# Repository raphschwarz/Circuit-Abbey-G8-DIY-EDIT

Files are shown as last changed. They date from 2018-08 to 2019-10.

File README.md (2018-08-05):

# Circuit-Abbey-G8-DIY-EDIT
diy edit for Circuit Abbaye G8 clock divider eurorack module

JACKS CHANGED FOR THONKIKONS

ATMEGA164 package changed to TQFP44//

crystal is thru-hole

MAY2018//74AC244/74LS244 line driver footprint changed to a wider TSSOP to fit most 74LS244 wich are in a wider tssop20 package. 
should still work with the original part (74AC244MTC-ND) but also should fit the more common (SN74LS244DBR)

AUGUST2018// switch has been replaced by TL1105SP (612-TL1105SP-250) as on mutable instruments modules to match thonkikonn jacks height

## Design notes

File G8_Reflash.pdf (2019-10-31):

# G8 Re-Flashing Instructions

The G8 Clock divider uses an embedded processor running a program stored in its internal memory called ‘flash’. Updating this program is hence called ‘re-flashing’. To perform re-flashing you will need:

- The .HEX file to re-flash with
- A programmer compatible with AVRISPII
- A program to drive the programmer

For the program we use AVR Studio 4, mostly because we are used to it. You can use a newer version of AVR Studio, or a different program such as AVR Dude. The programming port is called ‘ISP’. Make sure your programmer can handle ISP. It is characterized by a 6-pin ribbon cable.

Fuse bits:

The fuse bits set processor parameters at program time. Here is a screen capture of AVR Studio 4:

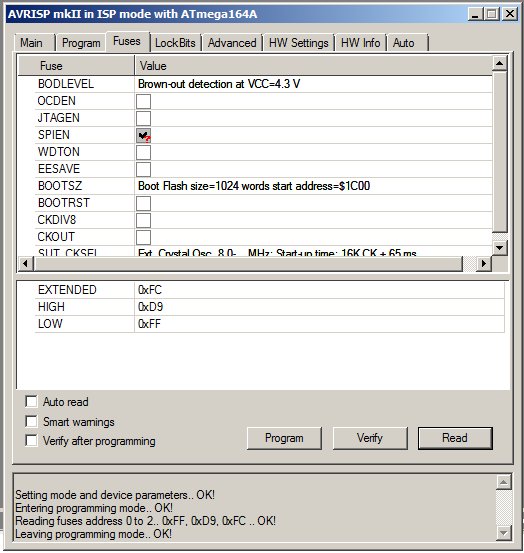
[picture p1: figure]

The fuse bits are very important to get right. Incorrect fuse bit will result in unit malfunction.

Procedure:

Attach the programmer to the G8 using the 6 pin ribbon cable. Pin 1 (red stripe) is denoted by the square pad on the left of the 6-pin header.

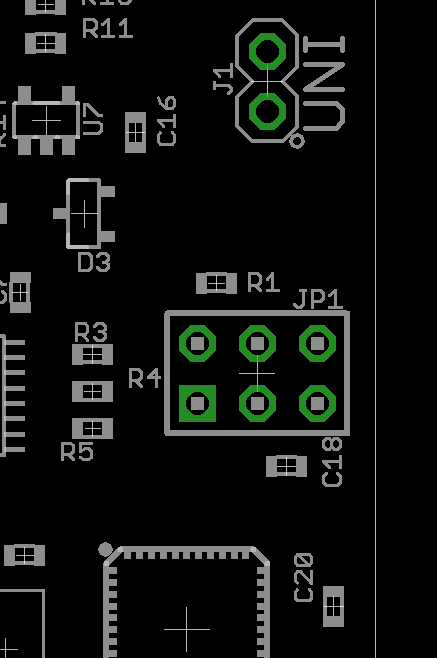
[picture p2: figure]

Power up the G8. If using an AVRISPII programmer there will be a green light indicating the programmer is happy.

Select the processor type: ATMEGA164A

Program and verify the flash memory

Program the fuse bits.

Power off the G8, disconnect the programmer, and re-power the G8. Check for operation.

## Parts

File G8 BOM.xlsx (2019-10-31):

Part | Value | Device | Package | Description | CA | DK | MF | MOUSER | MPN | OC_FARNELL | OC_NEWARK | VALUE
C1 | 18p | C0603 | C0603
C2 | 18p | C0603 | C0603
C3 | 100n | C0603 | C0603
C4 | 1n | C0603 | C0603
C5 | 100n | C0603 | C0603
C6 | 100n | C0603 | C0603
C7 | 100n | C0603 | C0603
C8 | 100n | C0603 | C0603
C9 | 100n | C0603 | C0603
C10 | 22u 25V | CPOL-USC | PANASONIC_C | POLARIZED CAPACITOR, American symbol |  | PCE3900CT-ND
C11 | 100n | C0603 | C0603
C12 | 100n | C0603 | C0603
C13 | 22u 25V | CPOL-USC | PANASONIC_C | POLARIZED CAPACITOR, American symbol |  | PCE3900CT-ND
C14 | 100n | C0603 | C0603
C15 | 100p | C0603 | C0603
C16 | 100p | C0603 | C0603
C17 | 100n | C0603 | C0603
C18 | 100n | C0603 | C0603
C19 | 100n | C0603 | C0603
C20 | 100n | C0603 | C0603
C21 | 100n | C0603 | C0603
D1 | BAS40-04 | BAS40-04 | SOT23 | Silicon Schottky Diodes
D2 | BAS40-04 | BAS40-04 | SOT23 | Silicon Schottky Diodes
D3 | BAS40-04 | BAS40-04 | SOT23 | Silicon Schottky Diodes
D4 | SS14 | T100331 | SMA-DO214AC | SS14 Schottky diode | T100331 |  |  |  |  |  |  | SS14
D5 | SS14 | T100331 | SMA-DO214AC | SS14 Schottky diode | T100331 |  |  |  |  |  |  | SS14
J1 | MA02-1-OCT | MA02-1-OCT | MA02-1-OCT
J3 |  | MA05-2 | MA05-2 | PIN HEADER
JP1 | AVR-ISP-6VERT | AVR-ISP-6VERT | AVR-ISP-6 | AVR ISP-6 Serial Programming Header
Q1 | 20M | TXC_7A | TXC_7A | Crystal 5x3.2 SMD |  |  |  | 717-7A-20.000MAAJ-T
R1 | 10K | R0603 | R0603
R2 | 10K | R0603 | R0603
R3 | 0R0 | R0603 | R0603
R4 | 0R0 | R0603 | R0603
R5 | 0R0 | R0603 | R0603
R6 | 10K | R0603 | R0603
R7 | 2K | R0603 | R0603
R8 | 2K | R0603 | R0603
R9 | 2K | R0603 | R0603
R10 | 100K | R0603 | R0603
R11 | 30K1 | R0603 | R0603
R12 | 1K | R0603 | R0603
R13 | 10K | R0603 | R0603
R14 | 20K | R0603 | R0603
R15 | 20K | R0603 | R0603
R16 | 2K | R0603 | R0603
R17 | 1 | R0603 | R0603
R18 | 1 | R0603 | R0603
R19 | 10K | R0603 | R0603
R20 | 10K | R0603 | R0603
R21 | 100K | R0603 | R0603
RN1 | 1.8K | CTS742C083 | CTS742C083 | Chip Resistor Array 4 Single Resistor |  |  |  |  |  | unknown | unknown
RN2 | 1.8K | CTS742C083 | CTS742C083 | Chip Resistor Array 4 Single Resistor |  |  |  |  |  | unknown | unknown
RN3 | 1.8K | CTS742C083 | CTS742C083 | Chip Resistor Array 4 Single Resistor |  |  |  |  |  | unknown | unknown
RN4 | 1.8K | CTS742C083 | CTS742C083 | Chip Resistor Array 4 Single Resistor |  |  |  |  |  | unknown | unknown
RN5 | 1.8K | CTS742C083 | CTS742C083 | Chip Resistor Array 4 Single Resistor |  |  |  |  |  | unknown | unknown
RN6 | 1.8K | CTS742C083 | CTS742C083 | Chip Resistor Array 4 Single Resistor |  |  |  |  |  | unknown | unknown
SV1 |  | MA05-2 | MA05-2 | PIN HEADER
SV2 |  | MA08-1-O | MA08-OCT | PIN HEADER
SV3 |  | MA08-1-O | MA08-OCT | PIN HEADER
SV4 |  | MA08-1-O | MA08-OCT | PIN HEADER
SV5 |  | MA08-1-O | MA08-OCT | PIN HEADER
U1 | 74HC595 | 74595DT | TSSOP16 | 8-bit SHIFT REGISTER, output latch
U2 | ATMEGA164-20M | ATMEGA644-20M | MLF44 | MICROCONTROLLER
U3 | 74HC595 | 74595DT | TSSOP16 | 8-bit SHIFT REGISTER, output latch
U4 | 74HC595 | 74595DT | TSSOP16 | 8-bit SHIFT REGISTER, output latch
U5 | 74LVC1G14 | 74LVC1G14 | SOT23-5L
U6 | 74LVC2G14DBV | 74LVC2G14DBV | SOT23-6
U7 | OPA171 | AD8031RJ | SOT23-5 | 2.7 V, 800 ?A, 80 MHz Rail-to-Rail I/O Amplifiers |  |  |  |  | AD8031ARTZ-REEL7 | 1660972 | 84R8399
U8 | LM4040C25IDBZR | LM4041A12DBZ | DBZ_R-PDSO-G3 | PRECISION MICROPOWER SHUNT VOLTAGE REFERENCE |  |  |  |  | LM4041A12IDBZR | 1407949 | 58K5875
U9 | 78L05F | 78L05F | SOT89 | POSITOIV-VOLTAGE REGULATORS
U10 | 74HC595 | 74595DT | TSSOP16 | 8-bit SHIFT REGISTER, output latch
U11 | 74244 | 74244 | TSSOP20 | Octal BUFFER and LINE DRIVER, 3-state
Switch |  | TL1105SPF250Q |  | 612-TL1105SP-250
Switch Cap |  |  | White | 612-1RWHT

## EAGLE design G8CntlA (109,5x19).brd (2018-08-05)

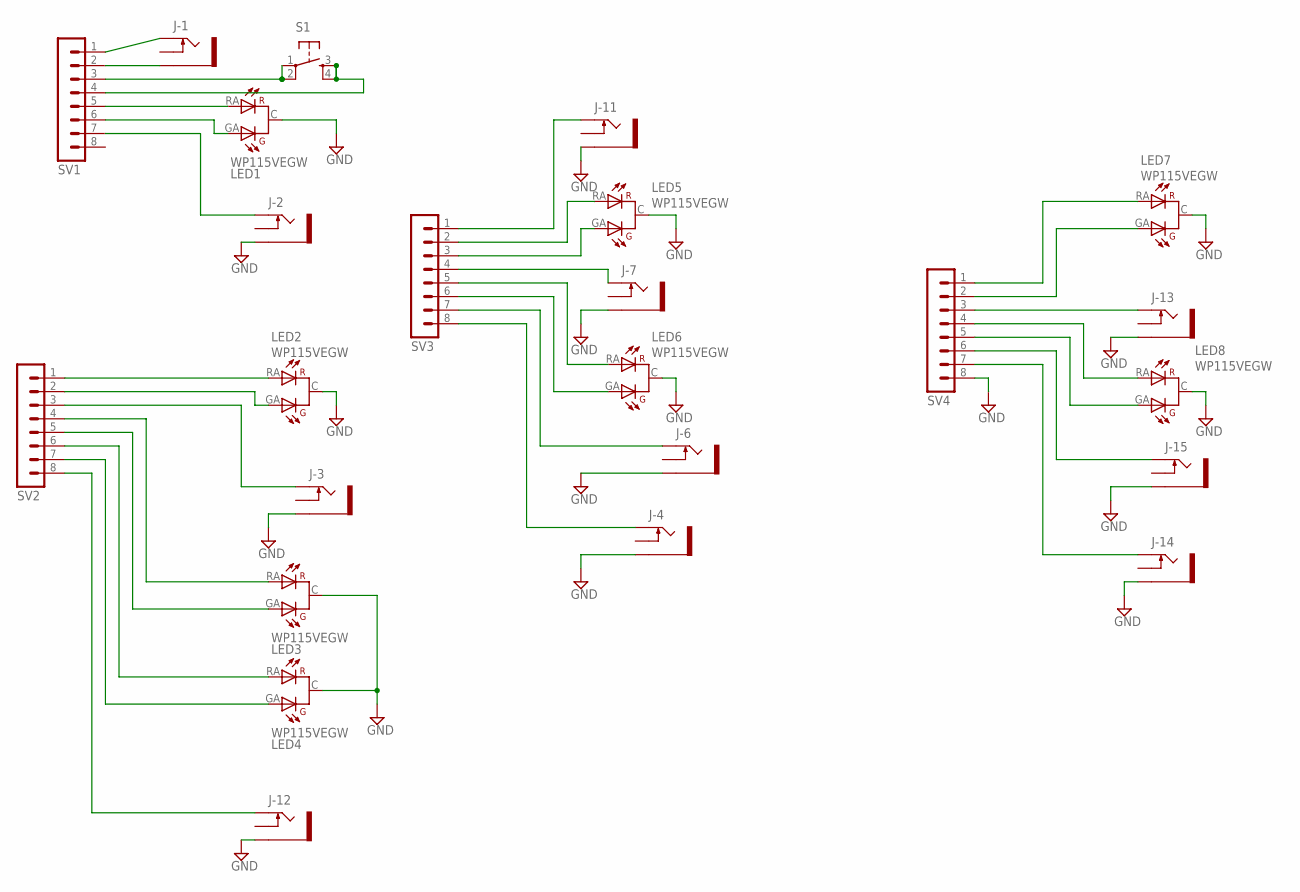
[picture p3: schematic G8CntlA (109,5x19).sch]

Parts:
J-1, J-2, J-3, J-4, J-6, J-7, J-11, J-12, J-13, J-14, J-15: THONKICONNNEW; WQP-PJ301M-12_JACK
LED1, LED2, LED3, LED4, LED5, LED6, LED7, LED8: WP115VEGW
S1: SPARKFUN_TAC_SWITCHPTH; SPARKFUN_TACTILE-PTH
SV1, SV2, SV3, SV4: MA08-1-O; MA08-OCT

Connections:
GND: J-2.P$3_SLEEVE (SLEEVE), J-3.P$3_SLEEVE (SLEEVE), J-4.P$3_SLEEVE (SLEEVE), J-6.P$3_SLEEVE (SLEEVE), J-7.P$3_SLEEVE (SLEEVE), J-11.P$3_SLEEVE (SLEEVE), J-12.P$3_SLEEVE (SLEEVE), J-13.P$3_SLEEVE (SLEEVE), J-14.P$3_SLEEVE (SLEEVE), J-15.P$3_SLEEVE (SLEEVE), LED1.C, LED2.C, LED3.C, LED4.C, LED5.C, LED6.C, LED7.C, LED8.C, SV4.8
unnamed: S1.1, S1.2, SV1.3
unnamed: S1.3, S1.4, SV1.4
unnamed: LED2.RA (GA), SV2.1
unnamed: J-1.P$1_TIP (TIP), SV1.1
unnamed: J-1.P$3_SLEEVE (SLEEVE), SV1.2
unnamed: J-2.P$1_TIP (TIP), SV1.7
unnamed: LED1.RA (GA), SV1.5
unnamed: LED1.GA (RA), SV1.6
unnamed: LED2.GA (RA), SV2.2
unnamed: J-3.P$1_TIP (TIP), SV2.3
unnamed: LED3.RA (GA), SV2.4
unnamed: LED3.GA (RA), SV2.5
unnamed: J-12.P$1_TIP (TIP), SV2.8
unnamed: LED4.RA (GA), SV2.6
unnamed: LED4.GA (RA), SV2.7
unnamed: J-11.P$1_TIP (TIP), SV3.1
unnamed: LED5.RA (GA), SV3.2
unnamed: LED5.GA (RA), SV3.3
unnamed: J-7.P$1_TIP (TIP), SV3.4
unnamed: LED6.RA (GA), SV3.5
unnamed: LED6.GA (RA), SV3.6
unnamed: J-6.P$1_TIP (TIP), SV3.7
unnamed: J-4.P$1_TIP (TIP), SV3.8
unnamed: J-15.P$1_TIP (TIP), SV4.6
unnamed: J-13.P$1_TIP (TIP), SV4.3
unnamed: J-14.P$1_TIP (TIP), SV4.7
unnamed: LED7.RA (GA), SV4.1
unnamed: LED7.GA (RA), SV4.2
unnamed: LED8.RA (GA), SV4.4
unnamed: LED8.GA (RA), SV4.5

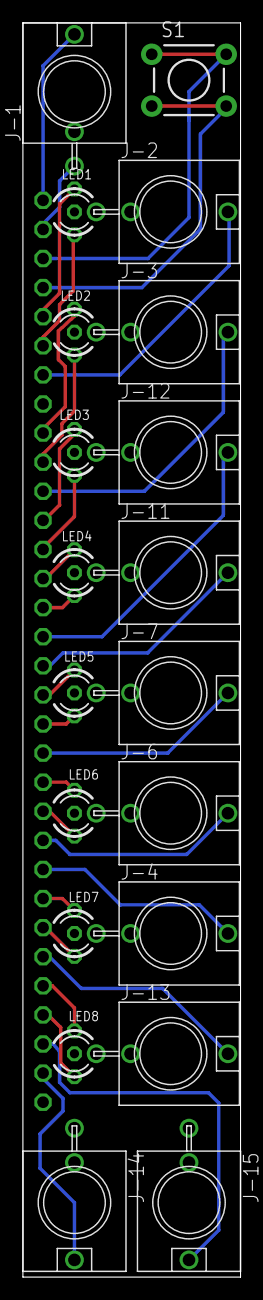
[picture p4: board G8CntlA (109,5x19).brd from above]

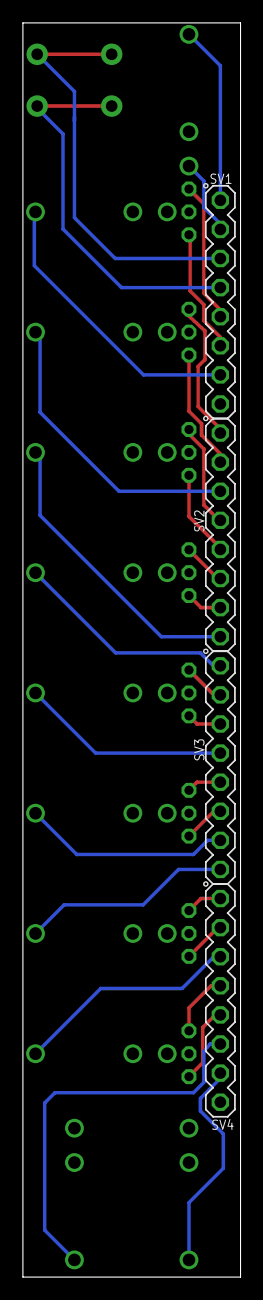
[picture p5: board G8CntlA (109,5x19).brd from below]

Board: 2 copper layers, 19.0 x 109.5 mm, 24 parts (4 on the bottom side), 31 nets.

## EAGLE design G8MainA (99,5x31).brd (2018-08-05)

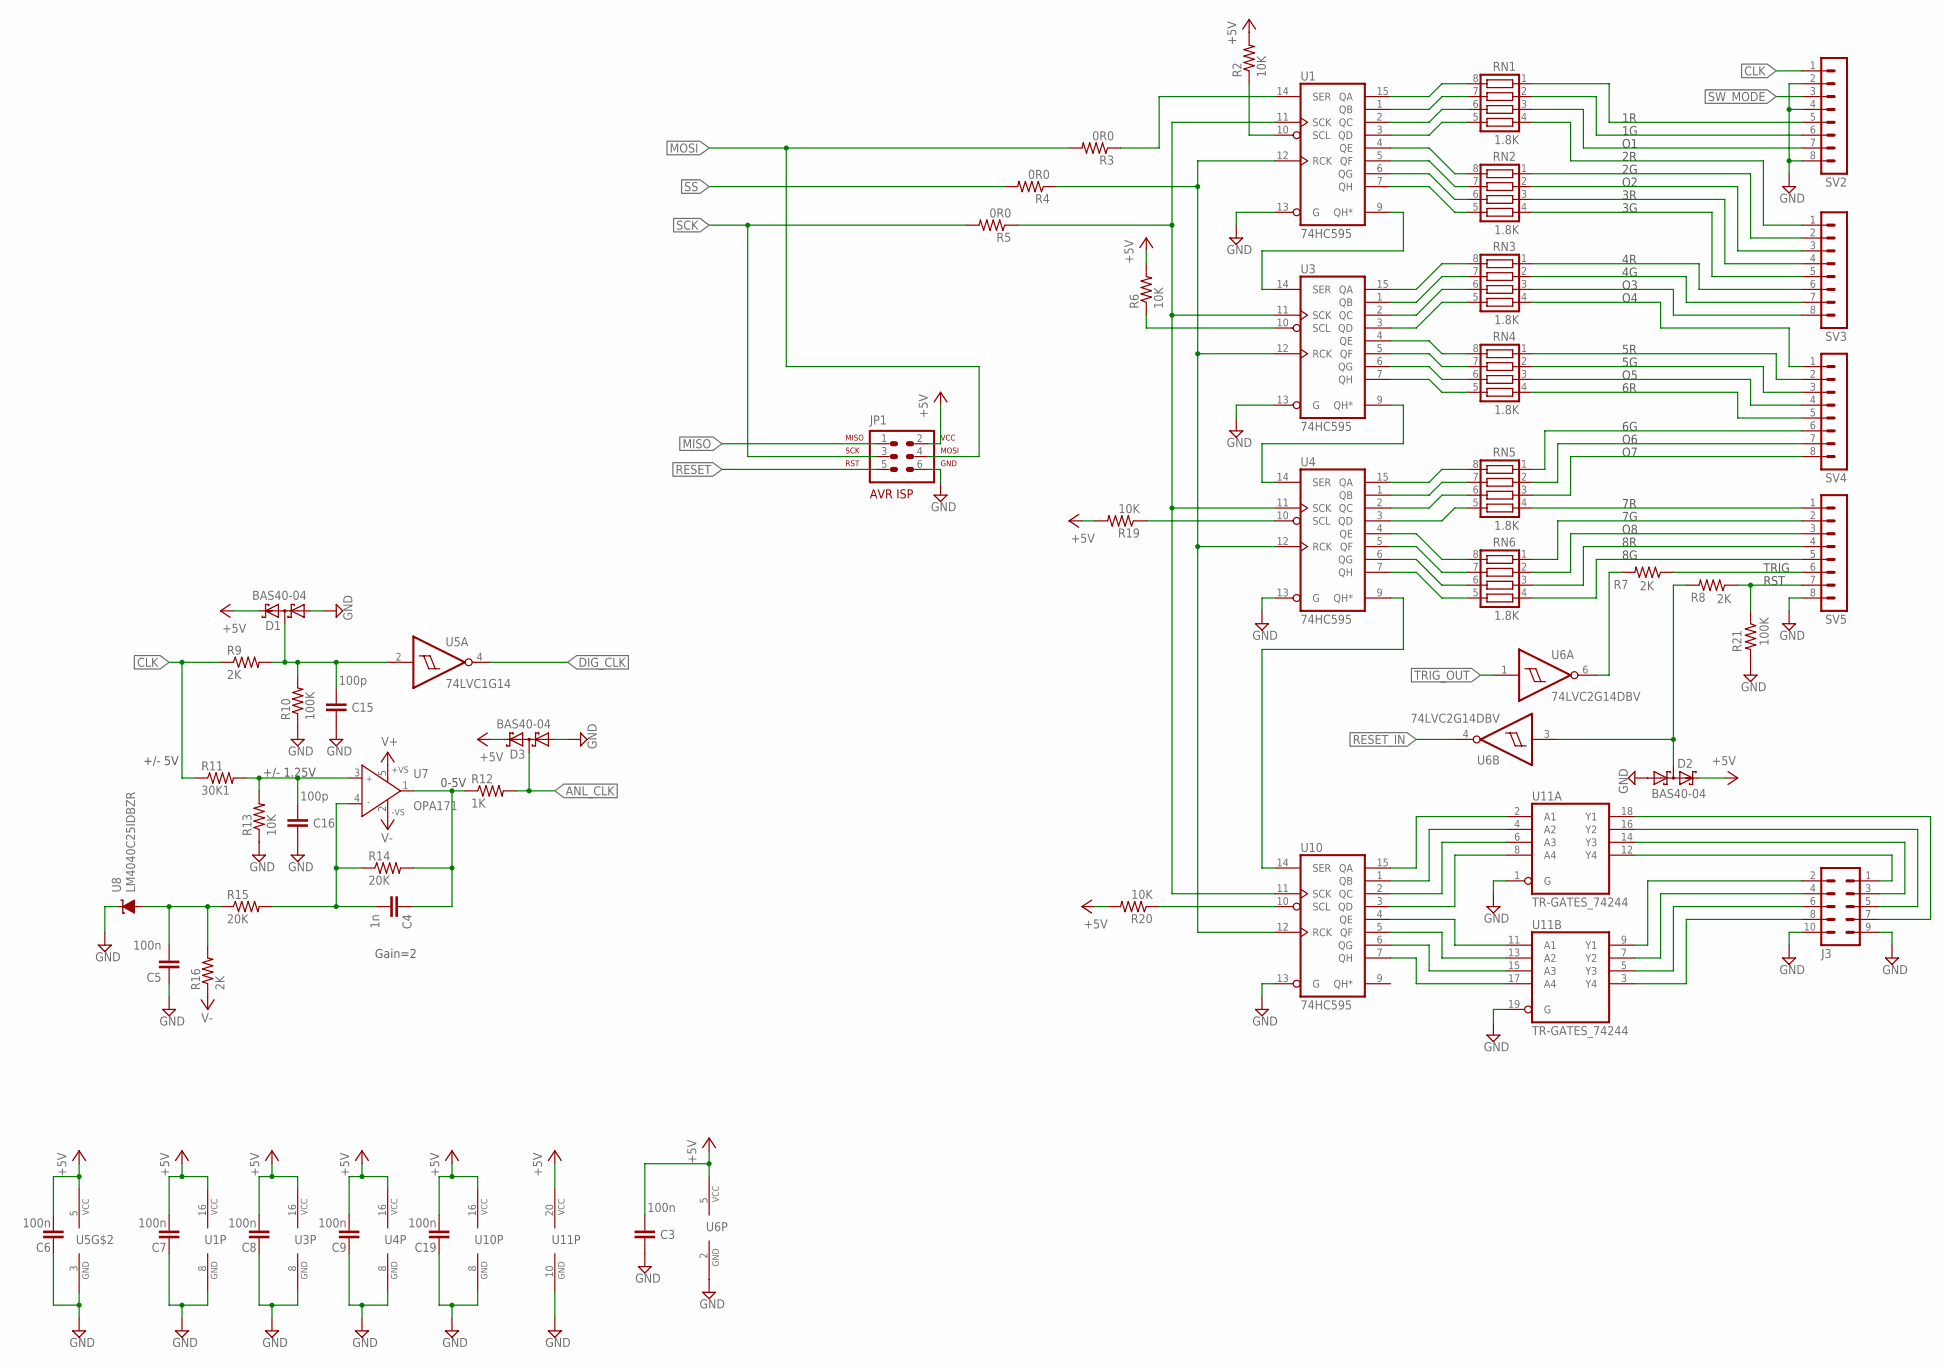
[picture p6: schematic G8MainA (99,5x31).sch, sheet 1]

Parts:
C3, C5, C6, C7, C8, C9, C19: 100n; C0603
C4: 1n; C0603
C15, C16: 100p; C0603
D1, D2, D3: BAS40-04; SOT23
J3: MA05-2
JP1: AVR-ISP-6VERT; AVR-ISP-6
R2, R6, R13, R19, R20: 10K; R0603
R3, R4, R5: 0R0; R0603
R7, R8, R9, R16: 2K; R0603
R10, R21: 100K; R0603
R11: 30K1; R0603
R12: 1K; R0603
R14, R15: 20K; R0603
RN1, RN2, RN3, RN4, RN5, RN6: 1.8K; CTS742C083
SV2, SV3, SV4, SV5: MA08-1-O; MA08-OCT
U1, U3, U4, U10: 74HC595; TSSOP16
U5: 74LVC1G14; SOT23-5L
U6: 74LVC2G14DBV; SOT23-6
U7: OPA171; SOT23-5
U8: LM4040C25IDBZR; DBZ_R-PDSO-G3
U11: TR-GATES_74244; TR-GATES_TSSOP20

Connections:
+5V: C3.2, C6.2, C7.2, C8.2, C9.2, C19.2, D1.2 (C2), D2.2 (C2), D3.2 (C2), JP1.2, R2.2, R6.2, R19.2, R20.2, U1.16 (VCC), U3.16 (VCC), U4.16 (VCC), U5.5 (VCC), U6.5 (VCC), U10.16 (VCC), U11.20 (VCC); also elsewhere on the board
ANL_CLK: D3.3 (C1A2), R12.2; also elsewhere on the board
CLK: R9.1, R11.1, SV2.1
DIG_CLK: U5.4 (O); also elsewhere on the board
GND: C3.1, C5.1, C6.1, C7.1, C8.1, C9.1, C15.1, C16.1, C19.1, D1.1 (A1), D2.1 (A1), D3.1 (A1), J3.9, J3.10, JP1.6, R10.1, R13.1, R21.2, SV2.2, SV2.4, SV2.8, SV5.8, U1.8 (GND), U1.13 (G), U3.8 (GND), U3.13 (G), U4.8 (GND), U4.13 (G), U5.3 (GND), U6.2 (GND), U8.1 (C), U10.8 (GND), U10.13 (G), U11.1 (G), U11.10 (GND), U11.19 (G); also elsewhere on the board
MISO: JP1.1; also elsewhere on the board
MOSI: JP1.4, R3.2; also elsewhere on the board
unnamed: U1.9 (QH*), U3.14 (SER)
unnamed: C15.2, D1.3 (C1A2), R9.2, R10.2, U5.2 (I)
unnamed: C16.2, R11.2, R13.2, U7.3 (IN+)
unnamed: C4.2, R14.1, R15.2, U7.4 (IN-)
unnamed: U3.9 (QH*), U4.14 (SER)
unnamed: R5.1, U1.11 (SCK), U3.11 (SCK), U4.11 (SCK), U10.11 (SCK)
unnamed: R4.1, U1.12 (RCK), U3.12 (RCK), U4.12 (RCK), U10.12 (RCK)
unnamed: R6.1, U3.10 (SCL)
unnamed: RN3.8, U3.15 (QA)
unnamed: RN2.8, U1.4 (QE)
unnamed: RN2.7, U1.5 (QF)
unnamed: RN2.6, U1.6 (QG)
unnamed: RN2.5, U1.7 (QH)
unnamed: RN1.5, U1.3 (QD)
unnamed: RN1.6, U1.2 (QC)
unnamed: C4.1, R12.1, R14.2, U7.1 (OUT)
unnamed: RN1.7, U1.1 (QB)
unnamed: RN1.8, U1.15 (QA)
unnamed: R3.1, U1.14 (SER)
unnamed: RN3.7, U3.1 (QB)
unnamed: RN3.6, U3.2 (QC)
unnamed: RN3.5, U3.3 (QD)
unnamed: RN4.8, U3.4 (QE)
unnamed: RN4.7, U3.5 (QF)
unnamed: RN4.6, U3.6 (QG)
unnamed: RN4.5, U3.7 (QH)
unnamed: RN5.8, U4.15 (QA)
unnamed: RN5.7, U4.1 (QB)
unnamed: RN5.6, U4.2 (QC)
unnamed: RN5.5, U4.3 (QD)
unnamed: RN6.8, U4.4 (QE)
unnamed: RN6.7, U4.5 (QF)
unnamed: RN6.6, U4.6 (QG)
unnamed: RN6.5, U4.7 (QH)
unnamed: RN1.1, SV2.5
unnamed: RN1.2, SV2.6
unnamed: RN1.3, SV2.7
unnamed: RN1.4, SV3.1
unnamed: RN2.1, SV3.2
unnamed: RN2.2, SV3.3
unnamed: RN2.3, SV3.4
unnamed: RN2.4, SV3.5
unnamed: RN3.1, SV3.6
unnamed: RN3.2, SV3.7
unnamed: RN3.3, SV3.8
unnamed: RN3.4, SV4.1
unnamed: RN4.1, SV4.2
unnamed: RN4.2, SV4.3
unnamed: RN4.3, SV4.4
unnamed: RN4.4, SV4.5
unnamed: RN5.1, SV4.6
unnamed: RN5.2, SV4.7
unnamed: RN5.3, SV4.8
unnamed: RN5.4, SV5.1
unnamed: RN6.1, SV5.2
unnamed: RN6.2, SV5.3
unnamed: RN6.3, SV5.4
unnamed: RN6.4, SV5.5
unnamed: R19.1, U4.10 (SCL)
unnamed: R2.1, U1.10 (SCL)
unnamed: C5.2, R15.1, R16.2, U8.2 (A)
unnamed: R8.1, R21.1, SV5.7
unnamed: R7.1, SV5.6
unnamed: R7.2, U6.6 (O)
unnamed: D2.3 (C1A2), R8.2, U6.3 (I)
unnamed: U4.9 (QH*), U10.14 (SER)
unnamed: R20.1, U10.10 (SCL)
unnamed: J3.7, U11.18 (Y1)
unnamed: U10.15 (QA), U11.2 (A1)
unnamed: U10.1 (QB), U11.4 (A2)
unnamed: U10.2 (QC), U11.6 (A3)
unnamed: U10.3 (QD), U11.8 (A4)
unnamed: U10.4 (QE), U11.11 (A1)
unnamed: U10.5 (QF), U11.13 (A2)
unnamed: U10.6 (QG), U11.15 (A3)
unnamed: U10.7 (QH), U11.17 (A4)
unnamed: J3.5, U11.16 (Y2)
unnamed: J3.3, U11.14 (Y3)
unnamed: J3.1, U11.12 (Y4)
unnamed: J3.2, U11.9 (Y1)
unnamed: J3.4, U11.7 (Y2)
unnamed: J3.6, U11.5 (Y3)
unnamed: J3.8, U11.3 (Y4)
RESET: JP1.5; also elsewhere on the board
RESET_IN: U6.4 (O); also elsewhere on the board
SCK: JP1.3, R5.2; also elsewhere on the board
SS: R4.2; also elsewhere on the board
SW_MODE: SV2.3; also elsewhere on the board
TRIG_OUT: U6.1 (I); also elsewhere on the board
V+: U7.5 (+VS); also elsewhere on the board
V-: R16.1, U7.2 (-VS); also elsewhere on the board

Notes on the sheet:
+/- 5V
+/- 1.25V
Gain=2
0-5V
TRIG
RST

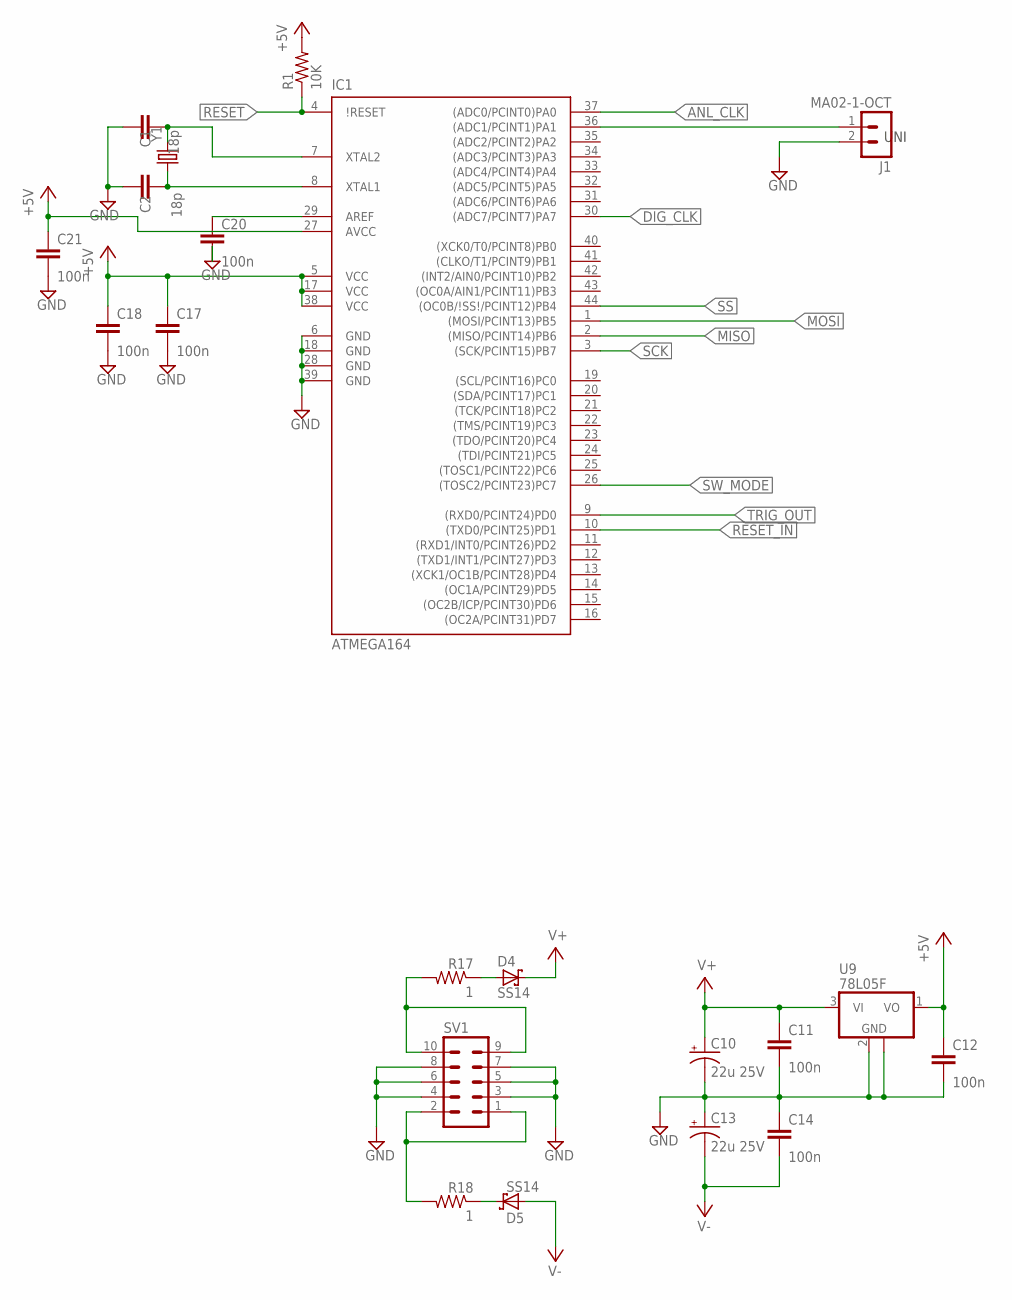
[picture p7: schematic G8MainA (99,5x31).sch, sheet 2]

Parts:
C1, C2: 18p; C0603
C10, C13: 22u 25V; PANASONIC_C
C11, C12, C14, C17, C18, C20, C21: 100n; C0603
D4, D5: SS14; SMA-DO214AC
IC1: ATMEGA164; TQFP44
J1: MA02-1-OCT
R1: 10K; R0603
R17, R18: 1; R0603
SV1: MA05-2
U9: 78L05F; SOT89
Y1: CRYSTALHC49UV; HC49U-V

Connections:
+5V: C12.1, C17.1, C18.1, C21.1, IC1.5 (VCC), IC1.17 (VCC), IC1.27 (AVCC), IC1.38 (VCC), R1.2, U9.1 (VO); also elsewhere on the board
ANL_CLK: IC1.37 ((ADC0/PCINT0)PA0); also elsewhere on the board
DIG_CLK: IC1.30 ((ADC7/PCINT7)PA7); also elsewhere on the board
GND: C1.1, C2.1, C10.-, C11.2, C12.2, C13.+, C14.1, C17.2, C18.2, C20.2, C21.2, IC1.6 (GND), IC1.18 (GND), IC1.28 (GND), IC1.39 (GND), J1.2, SV1.3, SV1.4, SV1.5, SV1.6, SV1.7, SV1.8, U9.2 (GND), U9.2@1 (GND); also elsewhere on the board
MISO: IC1.2 ((MISO/PCINT14)PB6); also elsewhere on the board
MOSI: IC1.1 ((MOSI/PCINT13)PB5); also elsewhere on the board
unnamed: C20.1, IC1.29 (AREF)
unnamed: C2.2, IC1.8 (XTAL1), Y1.1
unnamed: C1.2, IC1.7 (XTAL2), Y1.2
unnamed: IC1.36 ((ADC1/PCINT1)PA1), J1.1
unnamed: R18.2, SV1.1, SV1.2
unnamed: D4.A, R17.1
unnamed: R17.2, SV1.9, SV1.10
unnamed: D5.K (C), R18.1
RESET: IC1.4 (\!RESET), R1.1; also elsewhere on the board
RESET_IN: IC1.10 ((TXD0/PCINT25)PD1); also elsewhere on the board
SCK: IC1.3 ((SCK/PCINT15)PB7); also elsewhere on the board
SS: IC1.44 ((OC0B/\!SS\!/PCINT12)PB4); also elsewhere on the board
SW_MODE: IC1.26 ((TOSC2/PCINT23)PC7); also elsewhere on the board
TRIG_OUT: IC1.9 ((RXD0/PCINT24)PD0); also elsewhere on the board
V+: C10.+, C11.1, D4.K (C), U9.3 (VI); also elsewhere on the board
V-: C13.-, C14.2, D5.A; also elsewhere on the board

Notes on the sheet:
UNI

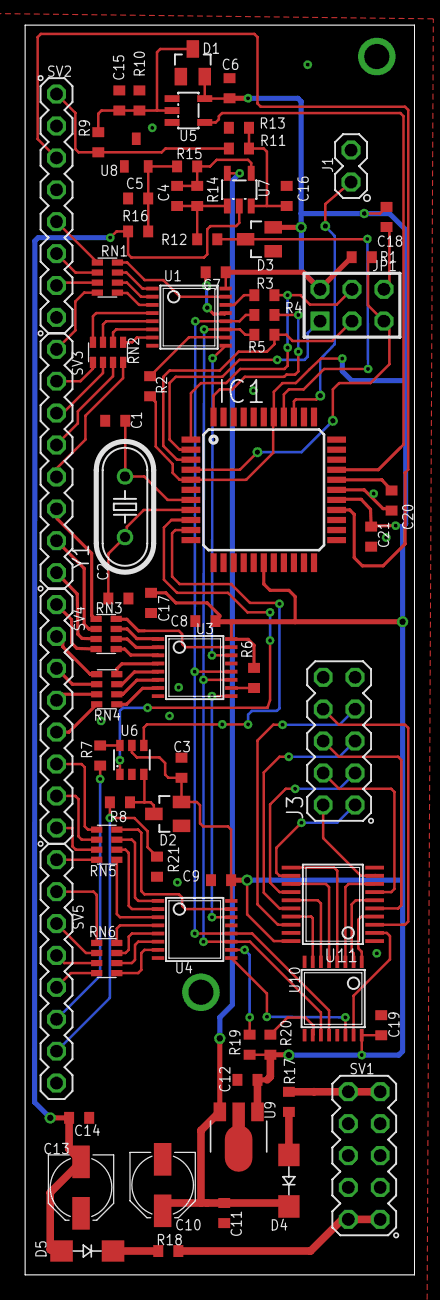
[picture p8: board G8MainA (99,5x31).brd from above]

Board: 2 copper layers, 31.0 x 99.5 mm, 73 parts (0 on the bottom side), 106 nets.

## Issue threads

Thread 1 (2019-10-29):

Circuit Abbey Website down

riverbasin, 2019-10-29:
Hello raphschwarz.  It looks like the Circuit Abbey website is down - hence all of the supporting material for this module, including firmware, are not available.  Do you know of an alternate source for supporting documentation and firmware? Best, riverbasin

raphschwarz, 2019-10-29:
Oups no I don’t !

I if doesn’t come back up I’ll ask around . I never actually had the panel made. So I never flashed the firmware on my build

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

riverbasin, 2019-10-29:
Okay, good to know.

You must be aware that Pusherman productions is producing this panel and
PCB as a DIY project? Here’s the link:

https://pushermanproductions.com/product/g8-clock-divider-pcb-aluminium-panel/

Best, Byron

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

raphschwarz, 2019-10-29:
Yes I know ! someone in pusherman groups must have it. If you find it don’t hesitate to send it to me I’ll host it with the board files so it is safely hosted for future generations ahaha

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

riverbasin, 2019-10-29:
Sounds great. I have contacted Phil at Pusherman as well as posted on the
Pusherman Facebook page. We’ll see what comes of it. I will keep you posted.

Also I did some more searching, and I found out that Circuit Abby is having
some medical issues. Check out their Facebook page. They seem in good
spirits, but their webpage will be down for a while.

Best, Byron

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

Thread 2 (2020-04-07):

Bom issues

thopa, 2020-04-07:
Bom issues:

Guess the BOM is from the old pcb by Circuit abbey, so this changes have not been done on the bom in this repo:

* ATMEGA644-20M  MLF44 and it should be TQFP44
* Crystal on BOM is smd on pcb is thru hole.

Thanks!

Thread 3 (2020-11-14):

Flashing HEX with AVRDUDE(SS)

flaminggarlic, 2020-11-14:
I tried to flash the hex using avrdude and ran into the issue that the ATMega164A is not a supported chip. This can either be addressed by changing the part in the bom to ATMega164P (which is supported and is identical in function with better power usage specs) or editing the avrdude.conf file from the AVRDUDE directory (or the AVRDUDESS directory if you use that GUI) and adding the following entry to support the chip:

```
#------------------------------------------------------------
# ATmega164A  ---- .kbv add a modified 164P entry
#------------------------------------------------------------

# close to ATmega16

part parent "m16"
    id               = "m164a";
    desc             = "ATmega164A";
    signature        = 0x1e 0x94 0x0f;

    progmodedelay       = 0;
    latchcycles         = 5;
    togglevtg           = 1;
    poweroffdelay       = 15;
    resetdelayms        = 1;
    allowfullpagebitstream = no;
    chip_erase_delay = 55000;

    ocdrev              = 3;
  ;

```

I was unable to add the extended fuse settings for some reason (greyed out field when the chip is selected), but that just governs brownout voltage, so I don't expect that to be much trouble. The Low and High fuses wrote as expected.

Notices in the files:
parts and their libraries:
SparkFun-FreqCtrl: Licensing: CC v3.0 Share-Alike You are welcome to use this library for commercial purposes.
